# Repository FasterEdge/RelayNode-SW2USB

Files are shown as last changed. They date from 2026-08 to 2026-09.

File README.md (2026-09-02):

<div align="center">

<h2>RelayNode - SW2USB</h2>
<h3>CH552G 原生 USB 四路开关输入节点（嘉立创 EDA 专业版硬件工程）</h3>
</div>

### 一、简介

**RelayNode-SW2USB** 是 FasterEdge 生态的硬件输入节点：以 **CH552G** 为控制核心，通过芯片原生 USB D+/D- 与主机通信，并提供 **4 路开关输入（SW1-SW4）**。硬件工程使用**嘉立创 EDA 专业版**（.eprj2）绘制。

- ✅ 嘉立创 EDA 专业版工程（`hardware/sw2usb_main.eprj2`），单文件可打开
- ✅ 主控 **CH552G**（增强型 8051、原生 USB 设备接口）
- ✅ USB-C 供电与通信，CC1/CC2 各使用 5.1kΩ 下拉
- ✅ 4 路开关输入 + 4 路配对 GND 端子
- ✅ 精简 BOM：15 个器件

### 二、目录结构

```
RelayNode-SW2USB/
├── hardware/                   # 嘉立创 EDA 专业版工程（.eprj2）与硬件相关文件
├── firmware/                   # CH552G Keil C51 USB HID 固件与烧录说明
├── BOM.txt                     # 元器件清单
├── LICENSE                     # Apache-2.0
└── README.md
```

### 三、使用说明

1. 下载安装**嘉立创 EDA 专业版**（立创EDA专业版）
2. 打开 `hardware/sw2usb_main.eprj2` 工程（原理图 / PCB 均已绘制）
3. 查看 `BOM.txt`：主控为 CH552G，USB-C 接口与 4 路开关/GND 端子均已列出
4. 按 `firmware/README.md` 使用 Keil C51 + WCH CH55x SDK 编译并烧录 USB HID 固件；SW1-SW4 以一字节位图上报

**硬件接口：**

- J1：USB-C（VBUS、D+、D-、CC1、CC2、GND、SHLD）
- J2-J5：SW1-SW4
- J6-J9：对应 GND
- R1/R2：CC1/CC2 5.1kΩ 下拉
- C1：VBUS 输入滤波；C2/C3：3V3/VBUS 去耦

### 四、版本

- **1.0.20260831**（与 FasterEdge 各平台版本同步）

### 五、姊妹项目

- **[FasterEdge MCU - PY32F003](https://github.com/FasterEdge/MCU-PY32F003)**：本板主控固件（Keil / PlatformIO）
- **[FasterEdge MCU - CH32V003](https://github.com/FasterEdge/MCU-CH32V003)**：可替代主控（RISC-V）
- **[FasterEdge](https://github.com/FasterEdge/FasterEdge)**：框架主仓库

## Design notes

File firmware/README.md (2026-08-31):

# RelayNode-SW2USB firmware

## Directory

- `CH552G/keil/`: CH552G Keil C51 application source integrated with the WCH CH55x USB Device/HID SDK.

Only the platform that maps cleanly to the real chip and vendor SDK is included. CH552G is an enhanced 8051 device; Keil C51 plus the official WCH CH55x SDK is the reliable path for native USB firmware.

## Behavior

- U1 pins 2/3/4/5 are CH552G P1.1/P1.2/P1.3/P1.4 and correspond to SW1/SW2/SW3/SW4.
- Inputs use internal pull-ups; an external switch closes to its paired GND terminal.
- A 25 ms debounce filter is applied.
- USB HID report ID 1 carries one data byte:
  - bit0: SW1
  - bit1: SW2
  - bit2: SW3
  - bit3: SW4
  - bit value 1 means closed/active.

## Keil C51 integration

1. Install Keil C51 and obtain the WCH CH552/CH554 SDK.
2. Create/open a CH552G project and add:
   - WCH startup file and `CH552.H`
   - WCH system/clock delay implementation (`CfgFsys`, `mDelaymS`)
   - WCH USB device core (`USBDeviceCfg`, endpoint and interrupt configuration)
   - HID descriptors and endpoint code
   - this repository's `CH552G/keil/User/main.c`
3. Implement the small adapter declared in `main.c`:

```c
void usb_hid_send_report(uint8_t report_id,
                         const uint8_t *data,
                         uint8_t length);
```

It must queue report ID 1 and the one-byte switch bitmap on the HID IN endpoint.
4. Build the `.hex` file.
5. Enter the CH552 bootloader according to the WCH bootloader procedure, connect USB-C, and flash with WCHISPTool/WCHISPStudio.

## Important hardware note

The board has no dedicated boot/reset pushbutton shown in the current BOM. If the factory-fresh chip does not enter the USB bootloader automatically, a temporary programmer/boot access method may be required. Verify the CH552G boot-entry pin and reset procedure from the exact WCH datasheet/bootloader version before mass production.

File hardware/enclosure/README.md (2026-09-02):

# RelayNode-SW2USB 外壳

3D 打印外壳，覆盖 `sw2usb_main` PCB（39.4 × 14.2 mm）。

> 来源：嘉立创 EDA 工程 `sw2usb_main.eprj2` 实测板框（1550 × 560 mil）。
> 风格：方形盒式上下盖，USB-C 从短边出线，8 个接线端子从顶板穿出。

## 目录结构

```
enclosure/
├── blender/                  # Blender 源文件
│   ├── enclosure.blend       # 主文件, PCB+元件占位 + 上下盖(双击打开)
│   └── enclosure.blend1      # Blender 自动生成
├── stl/
│   ├── top.stl               # 上盖 STL (996 三角面, 50 KB)
│   └── bottom.stl            # 底座 STL (348 三角面, 17 KB)
├── _shot_full.png             # Blender 视图截图(包含 PCB 参考)
├── _shot_shell.png           # 单独外壳视图截图
└── README.md                 # 本文件
```

## 几何参数

### 整体

| 维度 | 数值 |
|---|---|
| 外尺寸 | 45.4 × 20.2 × 11.6 mm |
| 壁厚 | 2.0 mm |
| 板下间隙 | 1.4 mm |
| 板上空间（内腔高度） | 4.6 mm |

### 上盖（`top.stl`）

- 顶部 **8 个端子方孔**（1.6 × 1.6 mm，2.54 mm 间距），两排
  - SW 排：J2–J5（y ≈ −6.86）
  - GND 排：J6–J9（y ≈ +7.11）
- 短边 **USB-C 通孔**：14.0 × 4.6 mm（y 范围 −7.0 至 +7.0 覆盖板 y 短边 99%，z 范围 0.8 至 5.4 贯穿短边壁厚），底部边缘对齐分模面
  - 短边壁只保留顶部 2 mm（z 5.4–7.4）作结构件，让 Type-C 头从底部露出 4.6 mm
  - 短边壁 y 端柱（y 端各 1.6 mm）保持完整宽度，结构强度充足
- **4 处卡扣凸耳**：+Y/−Y 外壁内侧 z 0.4–0.7 局部内凸 0.4 mm（与底座凹槽 y=9.7–10.1 完全嵌合，卡扣方向已修正）

### 底座（`bottom.stl`）

- 开口朝上，PCB 嵌入槽 41.4 × 16.2 × 3.0 mm
- **4 处滑动凹槽**：+Y/−Y 外壁 z 0.4–0.8 局部内凹 0.4 mm，与上盖凸耳配合

### 卡扣原理

滑动卡扣（snap-fit）：上盖从顶部压下，**凸耳（y=9.7–10.1 内凸）沿底座凹槽（y=9.7–10.1 内凹）滑入嵌合**，靠材料弹性 + 0.4 mm 过盈摩擦固定。
无需螺丝、无需胶水，可重复拆装。

> **暗病修复记录（2025-02）**：原设计凸耳方向错误（外凸 y=10.1–10.5 与凹槽内凹 y=9.7–10.1 方向相反，无法嵌合导致卡扣失效），已修正为凸耳内凸与凹槽同向嵌合。

> **建议**：如果打印后扣合困难，可将凹槽/凸耳处的 Z 范围微调 ±0.1 mm，或在切片器中设置 X/Y 水平补偿 +0.05 mm。

## 打印参数建议

| 参数 | 数值 |
|---|---|
| 材料 | PLA / PETG |
| 层高 | 0.2 mm |
| 壁（Wall） | ≥ 2 条（0.4 mm 喷嘴）或 4 条（0.8 mm） |
| 填充（Infill） | 20 % |
| 顶/底层（Top/Bottom） | ≥ 4 层 |
| 支撑 | 仅外壳打印**不需要**支撑（已验证无悬垂面） |
| 打印方向 | 上盖**顶面朝上**，底座**顶面（开口）朝上** |
| 水平扩展（Horizontal Expansion） | −0.05 mm（凹槽配合更顺滑） |

## 关键设计验证

| 检查项 | 结果 |
|---|---|
| 上下盖 mesh 水密（非流形/边界） | ✅ 0 / 0 |
| 顶板 8 个端子方孔位置 | ✅ 对准 J2–J9 |
| USB-C 通孔位置 | ✅ 对准 J1 短边 |
| 端子最高点（z=7.8）vs 内腔顶（z=5.4） | ✅ 穿出 2.4 mm（顶部方孔让位） |
| 元件最高点（USB 4.3 mm）vs 内腔顶（5.4 mm） | ✅ 余量 1.1 mm |
| STL 文件大小 / 三角形数 | top: 50 KB / 996 面；bottom: 17 KB / 348 面 |

## 嘉立创 EDA 协作工作流

外壳尺寸由嘉立创 EDA 实时读取，所有元件位置通过 JLC→Blender 坐标映射：

```
Blender x = (jL_x_mil − 725) × 0.0254
Blender y = −(jL_y_mil + 620) × 0.0254
Blender z = 0.8 + ½ × 元件高度（板上表面参考）
```

板中心对齐原点（0, 0, 0），X 轴为板长方向（39.4 mm），USB 短边朝 −X。

如需从 EDA 重新同步 PCB 元件位置，编辑 `enclosure.blend` 中 `PCB_Reference` 集合的子对象尺寸/位置即可。

## 后续可优化项

- [ ] 添加螺丝柱/M2 螺丝孔作为辅助固定（与卡扣并存）
- [ ] 端子区域加丝印标识（SW1–4 / GND1–4 / USB）
- [ ] PCB 定位柱（底部 2 定位销防止板晃动）
- [ ] 顶板 LOGO 凹刻（项目名 / 版本）

---

维护：硬件外壳与 PCB 同步更新。任何 PCB 修改后应重新核对 STL 关键尺寸（板框、端子位置、USB-C 位置）。

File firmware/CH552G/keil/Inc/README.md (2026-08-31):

# CH552G Keil 说明

本目录提供 CH552G SOP-16 的 Keil C51 入口代码。`User/main.c` 使用 WCH CH55x SDK 的系统和 USB 初始化接口；USB HID 描述符、端点配置和 `usb_hid_send_report()` 由 WCH CH55x USB Device/HID library 提供。

由于 WCH SDK 头文件、启动文件和 USB 描述符属于工具链/SDK 内容，未将第三方 SDK 二进制或库文件复制进仓库。请在 Keil 工程中加入对应 CH552/CH554 SDK 的 `CH552.H`、启动文件、USB Device 基础文件和 HID 类文件。

四路输入映射：P1.1/P1.2/P1.3/P1.4，分别对应 SW1/SW2/SW3/SW4；输入低电平表示开关闭合。HID 报告 ID 为 1，数据长度 1 字节，bit0..bit3 对应 SW1..SW4。

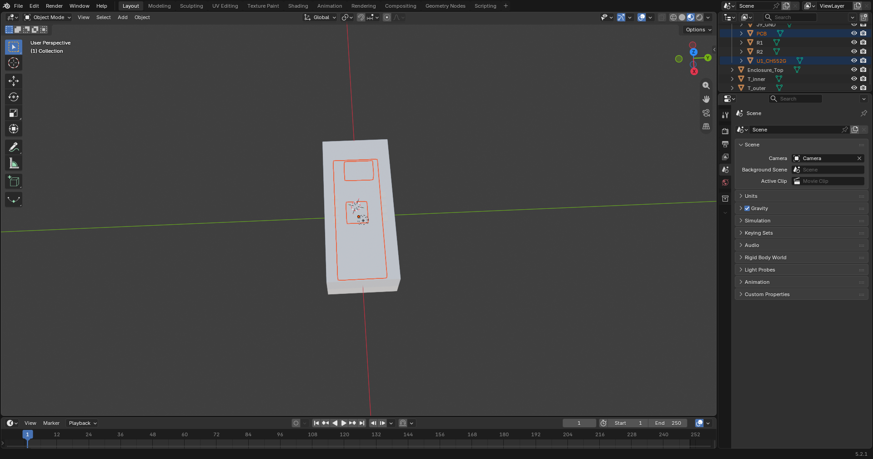
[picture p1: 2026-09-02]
hardware/enclosure/_shot_usbc_v3.png

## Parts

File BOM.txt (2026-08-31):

RelayNode - SW2USB BOM（以当前嘉立创 EDA 工程为准）

项目功能：CH552G 原生 USB 四路开关输入节点
默认装配：全部器件安装；CH552G 与 USB-C 的未使用引脚保持 NC

序号	位号	数量	类别/用途	参数或型号	制造商料号/选型	LCSC	封装
1	U1	1	USB MCU	CH552G	CH552G	C111292	SOP-16
2	J1	1	USB-C 母座	TYPE-C-31-M-12	TYPE-C-31-M-12	C165948	TYPE-C-SMD 16P
3	J2-J5	4	四路开关输入端子	单针 2.54mm	TS-101-T-B	C20381529	HDR-TH 1P 2.54mm
4	J6-J9	4	四路配对 GND 端子	单针 2.54mm	TS-101-T-B	C20381529	HDR-TH 1P 2.54mm
5	R1,R2	2	USB-C CC 下拉电阻	5.1kΩ，1%	0603WAF5101T5E	C23186	0603
6	C1	1	VBUS 输入滤波电容	10µF，10V，X5R/X7R	CL10A106KP8NNNC	C19702	0603
7	C2,C3	2	电源去耦电容	100nF，50V，X7R	CC0603KRX7R9BB104	C14663	0603

数量汇总：
- IC：U1，共 1 个
- 连接器：J1-J9，共 9 个
- 电阻：R1-R2，共 2 个
- 电容：C1-C3，共 3 个
- 总装配器件数：15 个

接口对应：
- J1：USB-C，包含 VBUS、D+、D−、CC1、CC2、GND 和独立 SHLD。
- J2：SW1；J3：SW2；J4：SW3；J5：SW4。
- J6-J9：四个配对 GND 端子，分别供外部开关回路使用。

采购与装配说明：
- U1 必须为 CH552G SOP-16；本项目不是 PY32F003 设计。
- R1/R2 必须为 5.1kΩ，不得误装成 5.1Ω或 51kΩ；它们分别将 CC1、CC2 下拉到 GND。
- J1 替代料必须保持 16P USB-C USB 2.0 引脚、固定脚和开槽尺寸完全一致，不能仅凭外观替换。
- J2-J9 使用同一单针通孔器件；若改用排针/排母，需复核针径、孔径、焊盘和板上机械位置。
- C1 建议耐压不低于 10V；C2/C3 为 100nF 去耦，装配时不得与 C1 混料。
- SHLD 是 USB-C 外壳屏蔽网络，设计中与 GND 分网；不要在装配或返修时随意短接。
- NC 引脚不安装额外器件，也不需要飞线连接。

网络与功能核对：
- USB-C D+/D− 直接连接 CH552G 原生 USB 引脚。
- USB-C VBUS 为板上输入电源，并由 C1/C3 滤波或去耦。
- CH552G 的 3V3 电源节点由 C2 去耦。
- SW1-SW4 为四路外部开关输入，具体内部上拉和 USB 协议由固件配置。

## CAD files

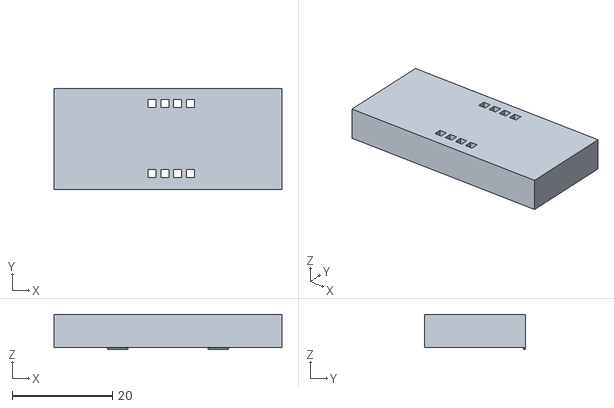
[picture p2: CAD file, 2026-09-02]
hardware/enclosure/stl/top.stl
45.4 x 20.2 x 7.00

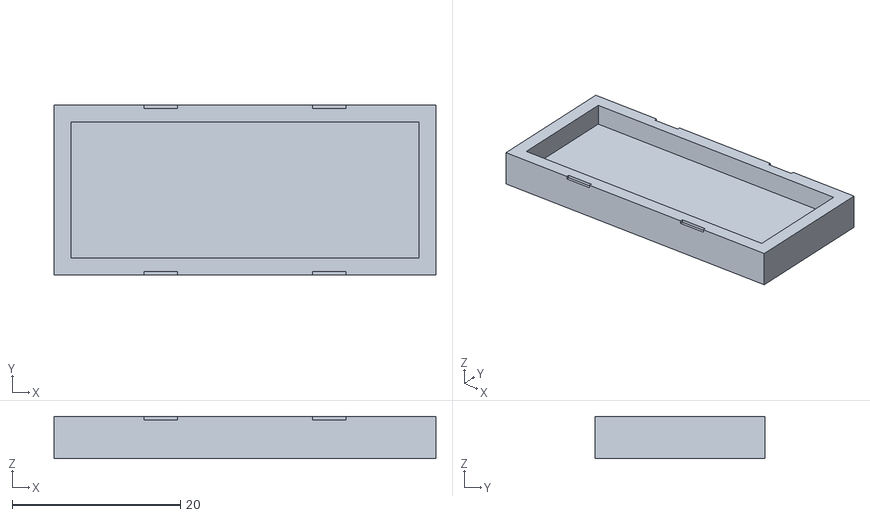
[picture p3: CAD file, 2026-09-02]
hardware/enclosure/stl/bottom.stl
45.4 x 20.2 x 5.00

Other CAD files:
hardware/enclosure/blender/enclosure.blend

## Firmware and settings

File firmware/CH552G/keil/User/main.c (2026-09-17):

/* FasterEdge 开源项目
 * GitHub: https://github.com/FasterEdge
 * Gitee:  https://gitee.com/FasterEdge
 */
#include <stdint.h>
#include "CH552.H"
#include "Debug.H"

/* USB HID transport is supplied by the WCH CH55x USB device library.
 * The hook must send report ID 1 followed by one byte of switch bits. */
extern void usb_hid_send_report(uint8_t report_id, const uint8_t *data, uint8_t length);

static uint8_t stable_state;
static uint8_t sampled_state;
static uint8_t debounce_ticks[4];

static uint8_t read_inputs(void) {
    uint8_t value = 0;
    if (!P1_1) value |= 0x01;
    if (!P1_2) value |= 0x02;
    if (!P1_3) value |= 0x04;
    if (!P1_4) value |= 0x08;
    return value;
}

static void send_switch_report(uint8_t value) {
    uint8_t report = value;
    usb_hid_send_report(1, &report, 1);
}

void main(void) {
    uint8_t i;
    CfgFsys();
    /* 四路开关输入引脚 P1.1-P1.4 配置为输入(DIR_PU 位=0 时内部上拉有效),
     * 开关接 GND 闭合时读低。旧实现 |= 0x1E 把输入脚置为输出: 复位后推挽
     * 高电平, read_inputs() 恒读到高致开关永远读不到闭合(功能失效), 且开关
     * 闭合到 GND 时与推挽高电平形成灌电流短路(引脚/开关损坏风险)。 */
    P1_DIR_PU &= (uint8_t)~0x1E;
    USBDeviceCfg();
    USBDeviceEndpCfg();
    USBDeviceIntCfg();
    USBDeviceCtrl(0x00);

    stable_state = read_inputs();
    sampled_state = stable_state;
    send_switch_report(stable_state);

    while (1) {
        uint8_t current = read_inputs();
        for (i = 0; i < 4; ++i) {
            uint8_t mask = (uint8_t)(1U << i);
            if ((current & mask) != (sampled_state & mask)) {
                sampled_state ^= mask;
                debounce_ticks[i] = 0;
            } else if (debounce_ticks[i] < 5) {
                ++debounce_ticks[i];
            } else if ((sampled_state & mask) != (stable_state & mask)) {
                stable_state = (stable_state & (uint8_t)~mask) | (sampled_state & mask);
                send_switch_report(stable_state);
            }
        }
        mDelaymS(5);
    }
}

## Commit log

2026-08-29 feat: RelayNode-SW2USB hardware update + docs (version 1.0.20260829)
2026-08-31 feat: add CH552G USB HID firmware — 4-switch byte bitmap report
    - Keil C51 + WCH CH55x SDK USB Device/HID firmware
    - SW1-SW4 on P1.1-P1.4, internal pull-ups, one-byte bitmap report
    - README with behavior/burn instructions; update root README software section
    [main.c]
2026-08-31 docs: 源码注释中加入 FasterEdge 组织标识与 GitHub/Gitee 链接
2026-09-02 chore: 目录整理 - software 重命名为 firmware，嘉立创 EDA 工程(.eprj2)移至 hardware/，同步更新 README
2026-09-02 Add 3D printed enclosure for RelayNode-SW2USB
    - 45.4x20.2x11.6mm square box, top + bottom shell
    - Wall thickness 2mm, snap-fit tabs (4x grooves on bottom, 4x lugs on top)
    - USB-C through-hole on -X short edge (9.4x3.5mm)
    - 8 terminal pass-through holes (1.6x1.6mm, 2.54mm pitch) on top
    2 rows: SW switch terminals (J2-J5) + GND terminals (J6-J9)
    - Enclosure dimensions derived from JLC EDA sw2usb_main project:
    PCB 39.37x14.22mm (1550x560 mil)
    - Both shells watertight (0 non-manifold / 0 boundary)
    - STL exports validated: bottom.stl 348 tris, top.stl 1224 tris
    [bottom.stl, enclosure.blend, top.stl]
2026-09-02 Enlarge USB-C opening on top shell (more accessible)
    - USB-C slot widened from 9.4mm to 13.0mm in Y direction
    - Covers 91% of board short-edge width (board y range ±7.11mm)
    - Hole y range: -6.5 to +6.5mm (centered at y=0, board short-edge)
    - Shell still watertight (0 non-manifold / 0 boundary)
    - STL: top.stl 1224 triangles, hole geometry validated
    [enclosure.blend, top.stl]
2026-09-02 Widen USB-C opening: 14x4.6mm, full short-edge coverage
    - USB-C hole expanded from y=±6.5 to y=±7.0 (14mm wide, covers 99% of board short-edge)
    - z range extended from 1.0-4.5 to 0.8-5.4 (4.6mm tall, through entire short wall thickness)
    - Short wall now has only top 2mm structural band (z 5.4-7.4)
    - Type-C connector fully exposed through the opening (4.6mm clearance for plug)
    - Short wall y-end pillars (1.6mm each end) remain intact for structural integrity
    - STL: top.stl 860 triangles (43 KB)
    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
    [enclosure.blend, top.stl]
2026-09-02 Fix snap-fit latch direction (was non-engaging)
    Bug found during design audit: top-cover latch lugs were OUTER bumps
    (y=10.1..10.5) while bottom grooves were INNER (y=9.7..10.1) - opposite
    directions, so the latches never engaged and the snap-fit was useless.
    Fix: lugs now INNER protrusions y=9.7..10.1, fully overlapping the
    bottom grooves -> proper snap-fit engagement.
    - Enclosure_Top rebuilt (488v/498f, watertight 0/0)
    - STL: top.stl 996 tris (was 1224/860), bottom.stl 348 tris
    - README updated
    [enclosure.blend, top.stl]
2026-09-04 docs: 新增 SECURITY.md 安全政策
    统一安全报告渠道 (GitHub Security Advisory + 邮件), 与
    FasterEdge 组织安全政策一致。避免未修复漏洞细节在公开
    渠道泄露。
2026-09-10 ci: 新增仓库完整性检查(固件依赖 WCH SDK 无法容器编译)
2026-09-17 fix(hw): 开关输入引脚 P1.1-P1.4 误配为输出 - 旧 P1_DIR_PU |= 0x1E 置输出致复位后推挽高电平, 开关闭合到 GND 形成灌电流短路且 read_inputs 恒读高(四路开关功能失效); 改为 P1_DIR_PU &= ~0x1E 输入+内部上拉, 删除对输入脚无意义的 MOD_OC 推挽配置
    [main.c]
2026-10-23 ci(deps): extend dependabot coverage to every manifest
    新增 1 条 update 配置：github-actions@/
    这些清单此前没有任何 dependabot 条目，CVE 扫描完全覆盖不到。
